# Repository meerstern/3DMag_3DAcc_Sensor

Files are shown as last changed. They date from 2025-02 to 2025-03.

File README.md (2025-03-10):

# 3D加速度/3D磁力センサ変換基板　
# 3D Magnetometer & 3D Accelerometer Board

## 概要 
  * ST製3D加速度/3D磁力センサ[ISM303DAC][1]を搭載した変換基板です 
  * 1つのセンサで3方向の磁界チャンネルと3方向の加速チャンネルを検出可能です    
  * 変換基板に電圧レベル変換を搭載しているため、3.3V/5V系に直結可能です
  * I2C/SPI/INTすべてのピンで電圧レベル変換を介してアクセス可能です  
  * I2CはGrove互換コネクタを搭載しています  
  * Arduino Uno等で利用可能なサンプルコードがあります  

## 仕様  
  * 磁界センサは最大±50ガウス磁気感度があります   
  * 加速度センサは±2/±4/±8/±16gから選択可能です  
  * 16bit分解能、256個のFIFOメモリを搭載しています    
  * SPI/I2Cシリアルインターフェイスを利用可能です
  * 急降下、動作、磁場検出のためのプログラマブルな割り込みに対応    
  * 電源電圧DC2.5V-5.0V  
  * サイズ30mm x25mm (突起部、コネクタ除く)

## 外観
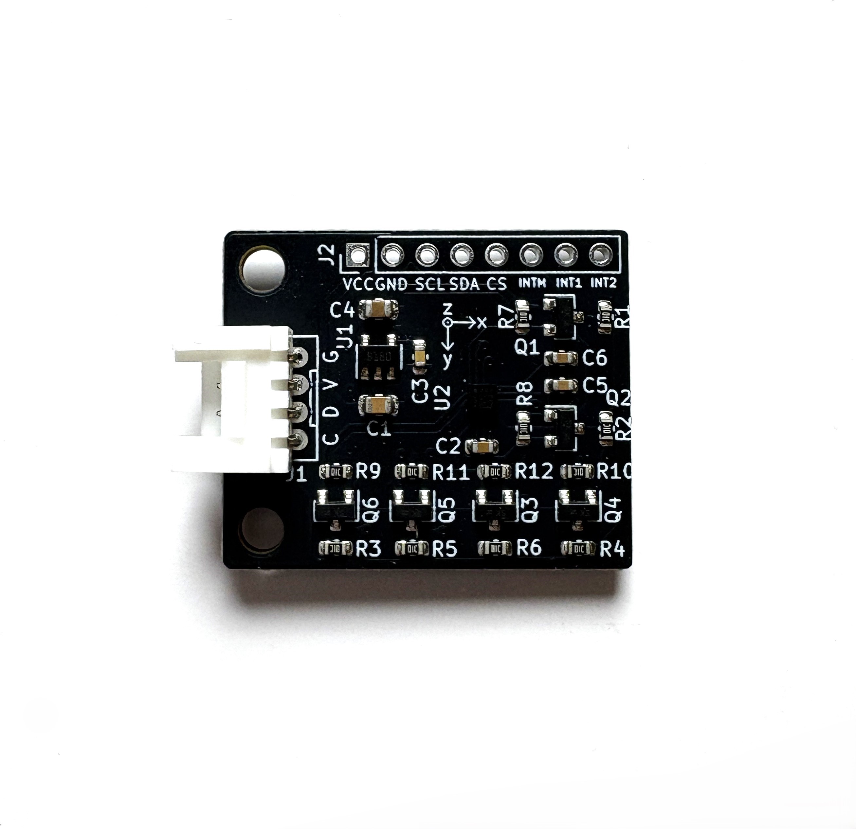
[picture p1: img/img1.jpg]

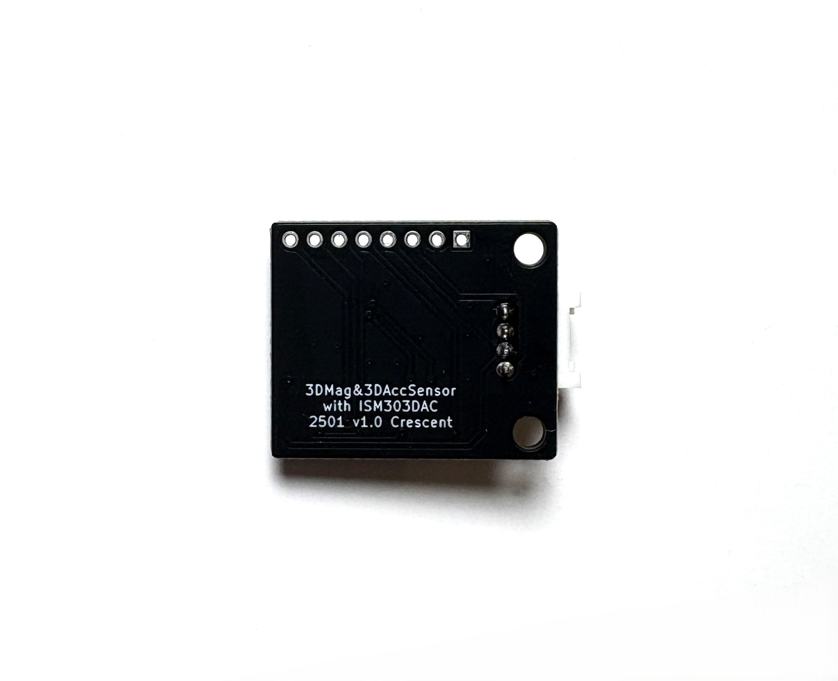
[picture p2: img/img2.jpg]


[1]: https://www.st.com/ja/mems-and-sensors/ism303dac.html

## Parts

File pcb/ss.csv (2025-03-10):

ID | 参照記号 | パッケージ | 数 | 名称 | Supplier and ref
1 | REF2,REF1 | MountingHole_3.2mm_M3 | 2 | MountingHole_3.2mm_M3
2 | U2 | LGA12 | 1 | ISM303DAC
3 | U1 | SOT-23-5 | 1 | LD3985M18R_SOT23
4 | R12,R11,R10,R9,R8,R7,R6,R5,R4,R3,R2,R1 | R_0603_1608Metric | 12 | 10k
5 | Q6,Q5,Q4,Q3,Q2,Q1 | SOT-23 | 6 | Q_NMOS_GSD
6 | J2 | PinHeader_1x08_P2.54mm_Vertical | 1 | Pinheader
7 | J1 | GROVE | 1 | Grove
8 | C6,C5 | C_0603_1608Metric | 2 | 0.1u
9 | C4,C1 | C_0805_2012Metric | 2 | 10u
10 | C3 | C_0603_1608Metric | 1 | 0.01u
11 | C2 | C_0603_1608Metric | 1 | 0.22uF

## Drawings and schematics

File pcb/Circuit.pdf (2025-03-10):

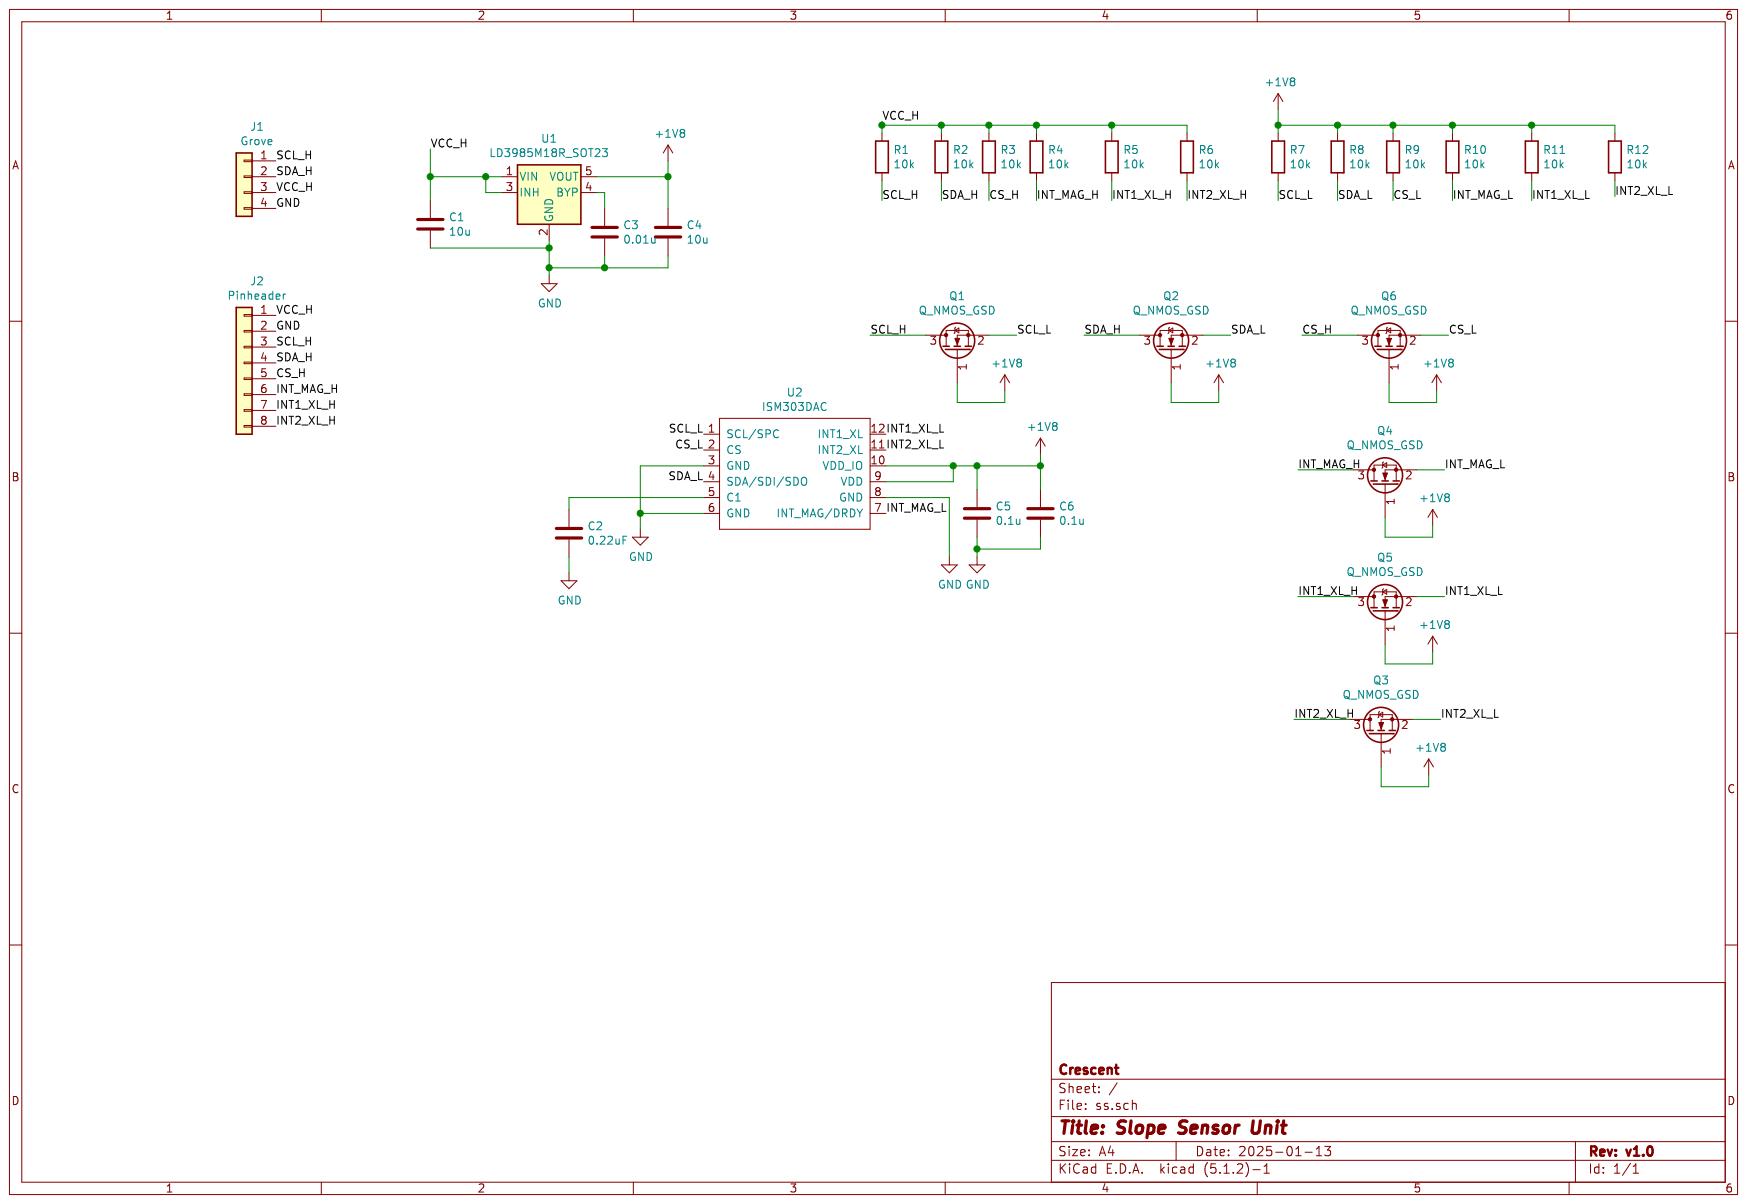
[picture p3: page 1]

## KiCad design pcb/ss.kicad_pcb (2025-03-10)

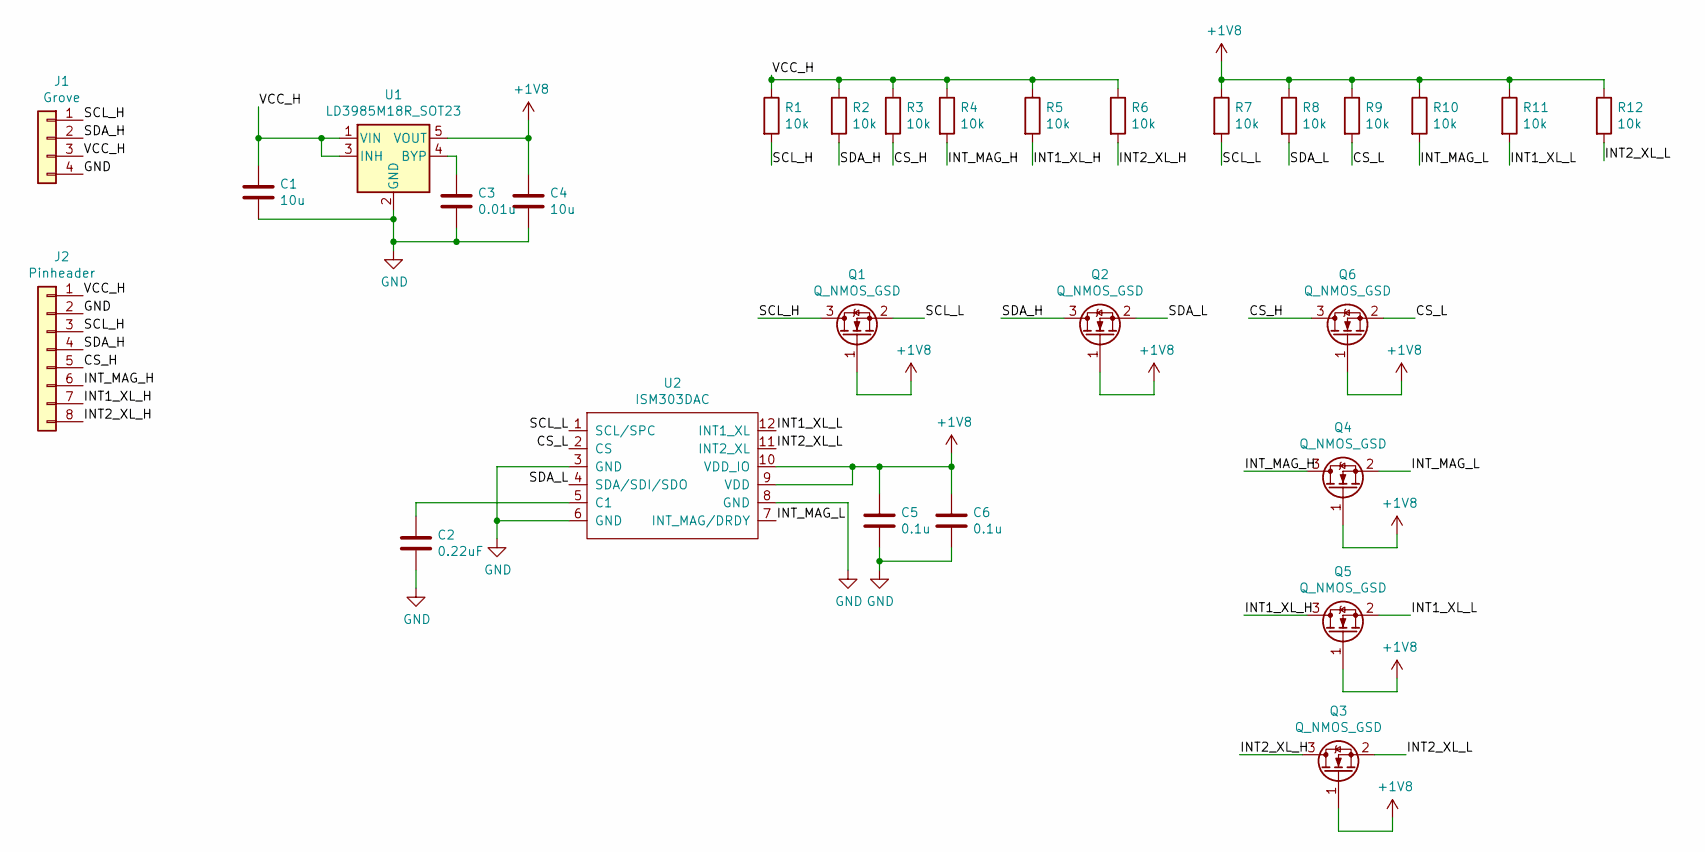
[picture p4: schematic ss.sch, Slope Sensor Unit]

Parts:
C1, C4: 10u; C_0805_2012Metric
C2: 0.22uF; C_0603_1608Metric
C3: 0.01u; C_0603_1608Metric
C5, C6: 0.1u; C_0603_1608Metric
J1: Grove; GROVE
J2: Pinheader; PinHeader_1x08_P2.54mm_Vertical
Q1, Q2, Q3, Q4, Q5, Q6: Q_NMOS_GSD; SOT-23
R1, R2, R3, R4, R5, R6, R7, R8, R9, R10, R11, R12: 10k; R_0603_1608Metric
U1: LD3985M18R_SOT23; SOT-23-5
U2: ISM303DAC; LGA12

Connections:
+1V8: C4.1, C5.1, C6.1, Q1.1 (G), Q2.1 (G), Q3.1 (G), Q4.1 (G), Q5.1 (G), Q6.1 (G), R7.1, R8.1, R9.1, R10.1, R11.1, R12.1, U1.5 (VOUT), U2.9 (VDD), U2.10 (VDD_IO)
/CS_H: J2.5, Q6.3 (D), R3.2
/CS_L: Q6.2 (S), R9.2, U2.2 (CS)
/INT1_XL_H: J2.7, Q5.3 (D), R5.2
/INT1_XL_L: Q5.2 (S), R11.2, U2.12 (INT1_XL)
/INT2_XL_H: J2.8, Q3.3 (D), R6.2
/INT2_XL_L: Q3.2 (S), R12.2, U2.11 (INT2_XL)
/INT_MAG_H: J2.6, Q4.3 (D), R4.2
/INT_MAG_L: Q4.2 (S), R10.2, U2.7 (INT_MAG/DRDY)
/SCL_H: J1.1, J2.3, Q1.3 (D), R1.2
/SCL_L: Q1.2 (S), R7.2, U2.1 (SCL/SPC)
/SDA_H: J1.2, J2.4, Q2.3 (D), R2.2
/SDA_L: Q2.2 (S), R8.2, U2.4 (SDA/SDI/SDO)
/VCC_H: C1.1, J1.3, J2.1, R1.1, R2.1, R3.1, R4.1, R5.1, R6.1, U1.1 (VIN), U1.3 (INH)
GND: C1.2, C2.2, C3.2, C4.2, C5.2, C6.2, J1.4, J2.2, U1.2 (GND), U2.3 (GND), U2.6 (GND), U2.8 (GND)
unnamed: C2.1, U2.5 (C1)
unnamed: C3.1, U1.4 (BYP)

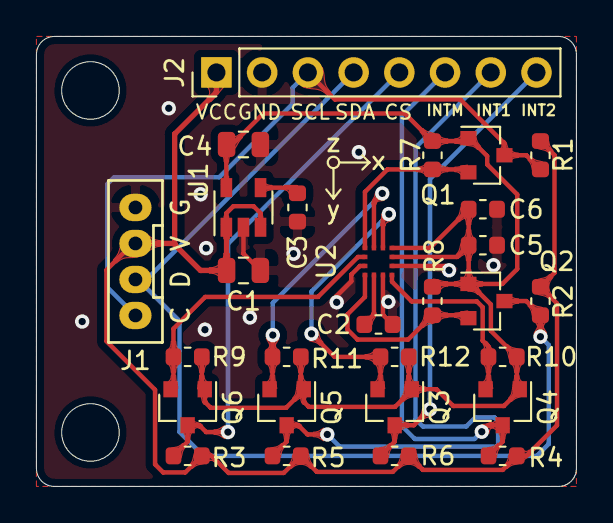
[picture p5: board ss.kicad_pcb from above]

Board: 2 copper layers, 30.0 x 25.0 mm, 30 parts (0 on the bottom side), 17 nets.

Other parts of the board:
REF1, REF2: MountingHole_3.2mm_M3

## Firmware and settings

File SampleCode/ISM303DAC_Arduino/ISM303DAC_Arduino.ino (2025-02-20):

/*
 ******************************************************************************
 * @file    read_data_polling.c
 * @author  Sensor Solutions Software Team
 * @brief   This file show the simplest way to get data from sensor.
 *
 ******************************************************************************
 * @attention
 *
 * <h2><center>&copy; Copyright (c) 2020 STMicroelectronics.
 * All rights reserved.</center></h2>
 *
 * This software component is licensed by ST under BSD 3-Clause license,
 * the "License"; You may not use this file except in compliance with the
 * License. You may obtain a copy of the License at:
 *                        opensource.org/licenses/BSD-3-Clause
 *
 ******************************************************************************
 */
/* Includes ------------------------------------------------------------------*/
#include <Arduino.h>
#include <Wire.h>
#include <string.h>
#include <stdio.h>
#include "ism303dac_reg.h"


typedef struct {
  //void   *hbus;
  uint8_t i2c_address;
  //GPIO_TypeDef *cs_port;
  //uint16_t cs_pin;
} sensbus_t;

/* Private macro -------------------------------------------------------------*/
#define    BOOT_TIME          20 //ms
//#define TX_BUF_DIM          100

#define    WAIT_TIME_XL     200 //ms
#define    WAIT_TIME_01     20 //ms
#define    WAIT_TIME_02     60 //ms

#define    SAMPLES_XL        5 //number of samples
#define    SAMPLES_MG       50 //number of samples
/* Self test limits. */
#define    MIN_ST_LIMIT_mg         70.0f
#define    MAX_ST_LIMIT_mg       1500.0f
#define    MIN_ST_LIMIT_mG         15.0f
#define    MAX_ST_LIMIT_mG        500.0f

/* Self test results. */
#define    ST_PASS     1U
#define    ST_FAIL     0U

/* Private variables ---------------------------------------------------------*/
static sensbus_t xl_bus =  {//&SENSOR_BUS,
                            (ISM303DAC_I2C_ADD_XL>>1)//,
                            //0,
                            //0
                           };
static sensbus_t mag_bus = {//&SENSOR_BUS,
                            (ISM303DAC_I2C_ADD_MG>>1)//,
                           // 0,
                           // 0
                           };


static int16_t data_raw_acceleration[3];
static int16_t data_raw_magnetic[3];
static float_t acceleration_mg[3];
static float_t magnetic_mG[3];
static uint8_t whoamI, rst;
//static uint8_t tx_buffer[TX_BUF_DIM];

/* Extern variables ----------------------------------------------------------*/

/* Private functions ---------------------------------------------------------*/
/*
 *   WARNING:
 *   Functions declare in this section are defined at the end of this file
 *   and are strictly related to the hardware platform used.
 *
 */
static int32_t platform_write(void *handle, uint8_t reg, const uint8_t *bufp,
                              uint16_t len);
static int32_t platform_read(void *handle, uint8_t reg, uint8_t *bufp,
                             uint16_t len);
static void tx_com( uint8_t *tx_buffer, uint16_t len );
static void platform_delay(uint32_t ms);
static void platform_init(void);
void ism303dac_read_data_polling(void);
void ism303dac_self_test(void);

/* Example --------------------------------------------------------------*/
void setup() 
{

  Serial.begin(9600);
  delay(10);
  Serial.println("ISM303DAC Demo");
  delay(10);
  ism303dac_self_test();
  ism303dac_read_data_polling();
}


void loop() 
{
  

}

/* Main Example --------------------------------------------------------------*/
void ism303dac_read_data_polling(void)
{
  /* Initialize mems driver interface */
  stmdev_ctx_t dev_ctx_xl;
  stmdev_ctx_t dev_ctx_mg;
  /* Initialize inertial sensors (IMU) driver interface */
  dev_ctx_xl.write_reg = platform_write;
  dev_ctx_xl.read_reg = platform_read;
  dev_ctx_xl.handle = (void *)&xl_bus;
  /* Initialize magnetic sensors driver interface */
  dev_ctx_mg.write_reg = platform_write;
  dev_ctx_mg.read_reg = platform_read;
  dev_ctx_mg.handle = (void *)&mag_bus;
  /* Initialize platform specific hardware */
  platform_init();
  /* Wait sensor boot time */
  platform_delay(BOOT_TIME);
  /* Check device ID */
  whoamI = 0;
  ism303dac_xl_device_id_get(&dev_ctx_xl, &whoamI);

  if ( whoamI != ISM303DAC_ID_XL )
    while (1); /*manage here device not found */

  whoamI = 0;
  ism303dac_mg_device_id_get(&dev_ctx_mg, &whoamI);

  if ( whoamI != ISM303DAC_ID_MG )
    while (1); /*manage here device not found */

  /* Restore default configuration */
  ism303dac_xl_reset_set(&dev_ctx_xl, PROPERTY_ENABLE);

  do {
    ism303dac_xl_reset_get(&dev_ctx_xl, &rst);
  } while (rst);

  ism303dac_mg_reset_set(&dev_ctx_mg, PROPERTY_ENABLE);

  do {
    ism303dac_mg_reset_get(&dev_ctx_mg, &rst);
  } while (rst);

  /* Enable Block Data Update */
  ism303dac_xl_block_data_update_set(&dev_ctx_xl, PROPERTY_ENABLE);
  ism303dac_mg_block_data_update_set(&dev_ctx_mg, PROPERTY_ENABLE);
  /* Set full scale */
  ism303dac_xl_full_scale_set(&dev_ctx_xl, ISM303DAC_XL_2g);
  /* Configure filtering chain */
  /* Accelerometer - High Pass / Slope path */
  //ism303dac_xl_hp_path_set(&dev_ctx_xl, ISM303DAC_HP_ON_OUTPUTS);
  /* Set / Reset magnetic sensor mode */
  ism303dac_mg_set_rst_mode_set(&dev_ctx_mg,
                                ISM303DAC_MG_SENS_OFF_CANC_EVERY_ODR);
  /* Enable temperature compensation on mag sensor */
  ism303dac_mg_offset_temp_comp_set(&dev_ctx_mg, PROPERTY_ENABLE);
  /* Set Output Data Rate */
  ism303dac_xl_data_rate_set(&dev_ctx_xl, ISM303DAC_XL_ODR_100Hz_LP);
  ism303dac_mg_data_rate_set(&dev_ctx_mg, ISM303DAC_MG_ODR_10Hz);
  /* Set magnetometer in continuous mode */
  ism303dac_mg_operating_mode_set(&dev_ctx_mg,
                                  ISM303DAC_MG_CONTINUOUS_MODE);

  /* Read samples in polling mode (no int) */
  while (1) {
    /* Read output only if new value is available */
    ism303dac_reg_t reg;
    ism303dac_xl_status_reg_get(&dev_ctx_xl, &reg.status_a);

    if (reg.status_a.drdy) {
      /* Read acceleration data */
      memset(data_raw_acceleration, 0x00, 3 * sizeof(int16_t));
      ism303dac_acceleration_raw_get(&dev_ctx_xl, data_raw_acceleration);
      acceleration_mg[0] = ism303dac_from_fs2g_to_mg(
                             data_raw_acceleration[0]);
      acceleration_mg[1] = ism303dac_from_fs2g_to_mg(
                             data_raw_acceleration[1]);
      acceleration_mg[2] = ism303dac_from_fs2g_to_mg(
                             data_raw_acceleration[2]);
      //Arduino Not Supportted snprintf float
      //snprintf((char *)tx_buffer, sizeof(tx_buffer),
      //        "Acceleration [mg]:%4.2f\t%4.2f\t%4.2f\r\n",
      //        acceleration_mg[0], acceleration_mg[1], acceleration_mg[2]);
      //tx_com( tx_buffer, strlen( (char const *)tx_buffer ) );
      Serial.print("Acceleration [mg]:\t\t");    
      Serial.print(acceleration_mg[0]);
      Serial.print(",\t\t");    
      Serial.print(acceleration_mg[1]);
      Serial.print(",\t\t");    
      Serial.print(acceleration_mg[2]);
      Serial.println();
    }

    ism303dac_mg_status_get(&dev_ctx_mg, &reg.status_reg_m);

    if (reg.status_reg_m.zyxda) {
      /* Read magnetic field data */
      memset(data_raw_magnetic, 0x00, 3 * sizeof(int16_t));
      ism303dac_magnetic_raw_get(&dev_ctx_mg, data_raw_magnetic);
      magnetic_mG[0] = ism303dac_from_lsb_to_mG( data_raw_magnetic[0]);
      magnetic_mG[1] = ism303dac_from_lsb_to_mG( data_raw_magnetic[1]);
      magnetic_mG[2] = ism303dac_from_lsb_to_mG( data_raw_magnetic[2]);
      //Arduino Not Supportted snprintf float
      //snprintf((char *)tx_buffer, sizeof(tx_buffer),
      //        "Magnetic field [mG]:%4.2f\t%4.2f\t%4.2f\r\n",
      //       magnetic_mG[0], magnetic_mG[1], magnetic_mG[2]);
      //tx_com( tx_buffer, strlen( (char const *)tx_buffer ) );
      Serial.print("Magnetic field [mG]:\t\t");    
      Serial.print(magnetic_mG[0]);
      Serial.print(",\t\t");    
      Serial.print(magnetic_mG[1]);
      Serial.print(",\t\t");    
      Serial.print(magnetic_mG[2]);
      Serial.println();
    }
  }
}

void ism303dac_self_test(void)
{
  stmdev_ctx_t dev_ctx_xl;
  stmdev_ctx_t dev_ctx_mg;
  uint8_t tx_buffer[1000];
  float_t meas_st_off[3];
  int16_t data_raw[3];
  float_t meas_st_on[3];
  ism303dac_reg_t reg;
  float_t test_val[3];
  uint8_t st_result;
  uint8_t i, j;
  /* Initialize inertial sensors (IMU) driver interface */
  dev_ctx_xl.write_reg = platform_write;
  dev_ctx_xl.read_reg = platform_read;
  dev_ctx_xl.handle = (void *)&xl_bus;
  /* Initialize magnetic sensors driver interface */
  dev_ctx_mg.write_reg = platform_write;
  dev_ctx_mg.read_reg = platform_read;
  dev_ctx_mg.handle = (void *)&mag_bus;
  /* Initialize self test results */
  st_result = ST_PASS;
  /* Initialize platform specific hardware */
  platform_init();
  /* Wait sensor boot time */
  platform_delay(BOOT_TIME);
  /* Check device ID */
  reg.byte = 0;
  ism303dac_xl_device_id_get(&dev_ctx_xl, &reg.byte);

  if ( reg.byte != ISM303DAC_ID_XL )
    while (1); /*manage here device not found */

  reg.byte = 0;
  ism303dac_mg_device_id_get(&dev_ctx_mg, &reg.byte);

  if ( reg.byte != ISM303DAC_ID_MG )
    while (1); /*manage here device not found */

  /* Restore default configuration */
  ism303dac_xl_reset_set(&dev_ctx_xl, PROPERTY_ENABLE);

  do {
    ism303dac_xl_reset_get(&dev_ctx_xl, &reg.byte);
  } while (reg.byte);

  ism303dac_mg_reset_set(&dev_ctx_mg, PROPERTY_ENABLE);

  do {
    ism303dac_mg_reset_get(&dev_ctx_mg, &reg.byte);
  } while (reg.byte);

  /* Enable Block Data Update */
  ism303dac_xl_block_data_update_set(&dev_ctx_xl, PROPERTY_ENABLE);
  ism303dac_mg_block_data_update_set(&dev_ctx_mg, PROPERTY_ENABLE);
  /*
   * START ACCELEROMETER SELF TEST PROCEDURE
   */
  /* Set full scale */
  ism303dac_xl_full_scale_set(&dev_ctx_xl, ISM303DAC_XL_2g);
  /* Set Output Data Rate. */
  ism303dac_xl_data_rate_set(&dev_ctx_xl, ISM303DAC_XL_ODR_50Hz_HR);
  /* Wait stable output */
  platform_delay(WAIT_TIME_XL);

  /* Check if new value available */
  do {
    ism303dac_xl_status_reg_get(&dev_ctx_xl, &reg.status_a);
  } while (!reg.status_a.drdy);

  /* Read dummy data and discard it */
  ism303dac_acceleration_raw_get(&dev_ctx_xl, data_raw);

  /* Read samples and get the average vale for each axis */
  for (i = 0; i < SAMPLES_XL; i++) {
    /* Check if new value available */
    do {
      ism303dac_xl_status_reg_get(&dev_ctx_xl, &reg.status_a);
    } while (!reg.status_a.drdy);

    /* Read data and accumulate the mg value */
    ism303dac_acceleration_raw_get(&dev_ctx_xl, data_raw);

    for (j = 0; j < 3; j++) {
      meas_st_off[j] += ism303dac_from_fs2g_to_mg(data_raw[j]);
    }
  }

  /* Calculate the mg average values */
  for (i = 0; i < 3; i++) {
    meas_st_off[i] /= SAMPLES_XL;
  }

  /* Enable Self Test positive (or negative) */
  ism303dac_xl_self_test_set(&dev_ctx_xl, ISM303DAC_XL_ST_POSITIVE);
  //ism303dac_xl_self_test_set(&dev_ctx_xl, ISM303DAC_ST_NEGATIVE);
  /* Wait stable output */
  platform_delay(WAIT_TIME_XL);

  /* Check if new value available */
  do {
    ism303dac_xl_status_reg_get(&dev_ctx_xl, &reg.status_a);
  } while (!reg.status_a.drdy);

  /* Read dummy data and discard it */
  ism303dac_acceleration_raw_get(&dev_ctx_xl, data_raw);

  /* Read samples and get the average vale for each axis */
  for (i = 0; i < SAMPLES_XL; i++) {
    /* Check if new value available */
    do {
      ism303dac_xl_status_reg_get(&dev_ctx_xl, &reg.status_a);
    } while (!reg.status_a.drdy);

    /* Read data and accumulate the mg value */
    ism303dac_acceleration_raw_get(&dev_ctx_xl, data_raw);

    for (j = 0; j < 3; j++) {
      meas_st_on[j] += ism303dac_from_fs2g_to_mg(data_raw[j]);
    }
  }

  /* Calculate the mg average values */
  for (i = 0; i < 3; i++) {
    meas_st_on[i] /= SAMPLES_XL;
  }

  /* Calculate the mg values for self test */
  for (i = 0; i < 3; i++) {
    test_val[i] = fabsf((meas_st_on[i] - meas_st_off[i]));
  }

  /* Check self test limit */
  for (i = 0; i < 3; i++) {
    if (( MIN_ST_LIMIT_mg > test_val[i] ) ||
        ( test_val[i] > MAX_ST_LIMIT_mg)) {
      st_result = ST_FAIL;
    }

    tx_com(tx_buffer, strlen((char const *)tx_buffer));
  }

  /* Disable Self Test */
  ism303dac_xl_self_test_set(&dev_ctx_xl, ISM303DAC_XL_ST_DISABLE);
  /* Disable sensor. */
  ism303dac_xl_data_rate_set(&dev_ctx_xl, ISM303DAC_XL_ODR_OFF);
  /*
   * END ACCELEROMETER SELF TEST PROCEDURE
   */
  /*
   * START MAGNETOMETER SELF TEST PROCEDURE
   */
  /* Temperature compensation enable */
  ism303dac_mg_offset_temp_comp_set(&dev_ctx_mg, PROPERTY_ENABLE);
  /* Set restore magnetic condition policy */
  ism303dac_mg_set_rst_mode_set(&dev_ctx_mg,
                                ISM303DAC_MG_SET_SENS_ODR_DIV_63);
  /* Set power mode */
  ism303dac_mg_power_mode_set(&dev_ctx_mg,
                              ISM303DAC_MG_HIGH_RESOLUTION);
  /* Set Output Data Rate */
  ism303dac_mg_data_rate_set(&dev_ctx_mg, ISM303DAC_MG_ODR_100Hz);
  /* Set Operating mode */
  ism303dac_mg_operating_mode_set(&dev_ctx_mg,
                                  ISM303DAC_MG_CONTINUOUS_MODE);
  /* Wait stable output */
  platform_delay(WAIT_TIME_01);

  /* Check if new value available */
  do {
    ism303dac_mg_status_get(&dev_ctx_mg, &reg.status_reg_m);
  } while (!reg.status_reg_m.zyxda);

  /* Read dummy data and discard it */
  ism303dac_magnetic_raw_get(&dev_ctx_mg, data_raw);
  /* Read samples and get the average vale for each axis */
  memset(meas_st_off, 0x00, 3 * sizeof(float));

  for (i = 0; i < SAMPLES_MG; i++) {
    /* Check if new value available */
    do {
      ism303dac_mg_status_get(&dev_ctx_mg, &reg.status_reg_m);
    } while (!reg.status_reg_m.zyxda);

    /* Read data and accumulate the mg value */
    ism303dac_magnetic_raw_get(&dev_ctx_mg, data_raw);

    for (j = 0; j < 3; j++) {
      meas_st_off[j] += ism303dac_from_lsb_to_mG(data_raw[j]);
    }
  }

  /* Calculate the mg average values */
  for (i = 0; i < 3; i++) {
    meas_st_off[i] /= SAMPLES_MG;
  }

  /* Enable Self Test */
  ism303dac_mg_self_test_set(&dev_ctx_mg, PROPERTY_ENABLE);
  /* Wait stable output */
  platform_delay(WAIT_TIME_02);

  /* Check if new value available */
  do {
    ism303dac_mg_status_get(&dev_ctx_mg, &reg.status_reg_m);
  } while (!reg.status_reg_m.zyxda);

  /* Read dummy data and discard it */
  ism303dac_magnetic_raw_get(&dev_ctx_mg, data_raw);
  /* Read samples and get the average vale for each axis */
  memset(meas_st_on, 0x00, 3 * sizeof(float));

  for (i = 0; i < SAMPLES_MG; i++) {
    /* Check if new value available */
    do {
      ism303dac_mg_status_get(&dev_ctx_mg, &reg.status_reg_m);
    } while (!reg.status_reg_m.zyxda);

    /* Read data and accumulate the mg value */
    ism303dac_magnetic_raw_get(&dev_ctx_mg, data_raw);

    for (j = 0; j < 3; j++) {
      meas_st_on[j] += ism303dac_from_lsb_to_mG(data_raw[j]);
    }
  }

  /* Calculate the mg average values */
  for (i = 0; i < 3; i++) {
    meas_st_on[i] /= SAMPLES_MG;
  }

  st_result = ST_PASS;

  /* Calculate the mg values for self test */
  for (i = 0; i < 3; i++) {
    test_val[i] = fabsf((meas_st_on[i] - meas_st_off[i]));
  }

  /* Check self test limit */
  for (i = 0; i < 3; i++) {
    if (( MIN_ST_LIMIT_mG > test_val[i] ) ||
        ( test_val[i] > MAX_ST_LIMIT_mG)) {
      st_result = ST_FAIL;
    }
  }

  /* Disable Self Test */
  ism303dac_mg_self_test_set(&dev_ctx_mg, PROPERTY_DISABLE);
  /* Disable sensor. */
  ism303dac_mg_operating_mode_set(&dev_ctx_mg, ISM303DAC_MG_POWER_DOWN);

  /*
   * END MAGNETOMETER SELF TEST PROCEDURE
   */

  /* Print self test result */
  if (st_result == ST_PASS) {
    //snprintf((char *)tx_buffer, sizeof(tx_buffer), "Self Test - PASS\r\n" );
    Serial.println("Self Test - PASS");
  }

  else {
    //snprintf((char *)tx_buffer, sizeof(tx_buffer), "Self Test - FAIL\r\n" );
    Serial.println("Self Test - FAIL");
  }

  //tx_com(tx_buffer, strlen((char const *)tx_buffer));
}

/*
 * @brief  Write generic device register (platform dependent)
 *
 * @param  handle    customizable argument. In this examples is used in
 *                   order to select the correct sensor bus handler.
 * @param  reg       register to write
 * @param  bufp      pointer to data to write in register reg
 * @param  len       number of consecutive register to write
 *
 */
static int32_t platform_write(void *handle, uint8_t reg, const uint8_t *bufp,
                              uint16_t len)
{
  sensbus_t *sensbus = (sensbus_t *)handle;

  Wire.beginTransmission(sensbus->i2c_address);
  Wire.write(reg);
  Wire.write(bufp, len);
  Wire.endTransmission();
  return 0;
}

/*
 * @brief  Read generic device register (platform dependent)
 *
 * @param  handle    customizable argument. In this examples is used in
 *                   order to select the correct sensor bus handler.
 * @param  reg       register to read
 * @param  bufp      pointer to buffer that store the data read
 * @param  len       number of consecutive register to read
 *
 */
static int32_t platform_read(void *handle, uint8_t reg, uint8_t *bufp,
                             uint16_t len)
{
  sensbus_t *sensbus = (sensbus_t *)handle;
  
  Wire.beginTransmission(sensbus->i2c_address);
  Wire.write(reg);
  Wire.endTransmission(false);
  
  Wire.requestFrom((uint8_t)sensbus->i2c_address, (uint8_t)len);

  while (Wire.available()) {
    *bufp = Wire.read();
    bufp++;
  }
  return 0;
}

/*
 * @brief  Write generic device register (platform dependent)
 *
 * @param  tx_buffer     buffer to transmit
 * @param  len           number of byte to send
 *
 */
static void tx_com(uint8_t *tx_buffer, uint16_t len)
{

}

/*
 * @brief  platform specific delay (platform dependent)
 *
 * @param  ms        delay in ms
 *
 */
static void platform_delay(uint32_t ms)
{
  delay(ms);
}

/*
 * @brief  platform specific initialization (platform dependent)
 */
static void platform_init(void)
{
  Wire.begin();
  Wire.setClock(100000);
}

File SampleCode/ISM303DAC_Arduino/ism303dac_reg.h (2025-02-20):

/**
  ******************************************************************************
  * @file    ism303dac_reg.h
  * @author  Sensors Software Solution Team
  * @brief   This file contains all the functions prototypes for the
  *          ism303dac_reg.c driver.
  ******************************************************************************
  * @attention
  *
  * <h2><center>&copy; Copyright (c) 2021 STMicroelectronics.
  * All rights reserved.</center></h2>
  *
  * This software component is licensed by ST under BSD 3-Clause license,
  * the "License"; You may not use this file except in compliance with the
  * License. You may obtain a copy of the License at:
  *                        opensource.org/licenses/BSD-3-Clause
  *
  ******************************************************************************
  */

/* Define to prevent recursive inclusion -------------------------------------*/
#ifndef ISM303DAC_REGS_H
#define ISM303DAC_REGS_H

#ifdef __cplusplus
extern "C" {
#endif

/* Includes ------------------------------------------------------------------*/
#include <stdint.h>
#include <stddef.h>
#include <math.h>

/** @addtogroup ISM303DAC
  * @{
  *
  */

/** @defgroup  Endianness definitions
  * @{
  *
  */

#ifndef DRV_BYTE_ORDER
#ifndef __BYTE_ORDER__

#define DRV_LITTLE_ENDIAN 1234
#define DRV_BIG_ENDIAN    4321

/** if _BYTE_ORDER is not defined, choose the endianness of your architecture
  * by uncommenting the define which fits your platform endianness
  */
//#define DRV_BYTE_ORDER    DRV_BIG_ENDIAN
#define DRV_BYTE_ORDER    DRV_LITTLE_ENDIAN

#else /* defined __BYTE_ORDER__ */

#define DRV_LITTLE_ENDIAN  __ORDER_LITTLE_ENDIAN__
#define DRV_BIG_ENDIAN     __ORDER_BIG_ENDIAN__
#define DRV_BYTE_ORDER     __BYTE_ORDER__

#endif /* __BYTE_ORDER__*/
#endif /* DRV_BYTE_ORDER */

/**
  * @}
  *
  */

/** @defgroup STMicroelectronics sensors common types
  * @{
  *
  */

#ifndef MEMS_SHARED_TYPES
#define MEMS_SHARED_TYPES

typedef struct
{
#if DRV_BYTE_ORDER == DRV_LITTLE_ENDIAN
  uint8_t bit0       : 1;
  uint8_t bit1       : 1;
  uint8_t bit2       : 1;
  uint8_t bit3       : 1;
  uint8_t bit4       : 1;
  uint8_t bit5       : 1;
  uint8_t bit6       : 1;
  uint8_t bit7       : 1;
#elif DRV_BYTE_ORDER == DRV_BIG_ENDIAN
  uint8_t bit7       : 1;
  uint8_t bit6       : 1;
  uint8_t bit5       : 1;
  uint8_t bit4       : 1;
  uint8_t bit3       : 1;
  uint8_t bit2       : 1;
  uint8_t bit1       : 1;
  uint8_t bit0       : 1;
#endif /* DRV_BYTE_ORDER */
} bitwise_t;

#define PROPERTY_DISABLE                (0U)
#define PROPERTY_ENABLE                 (1U)

/** @addtogroup  Interfaces_Functions
  * @brief       This section provide a set of functions used to read and
  *              write a generic register of the device.
  *              MANDATORY: return 0 -> no Error.
  * @{
  *
  */

typedef int32_t (*stmdev_write_ptr)(void *, uint8_t, const uint8_t *, uint16_t);
typedef int32_t (*stmdev_read_ptr)(void *, uint8_t, uint8_t *, uint16_t);
typedef void (*stmdev_mdelay_ptr)(uint32_t millisec);

typedef struct
{
  /** Component mandatory fields **/
  stmdev_write_ptr  write_reg;
  stmdev_read_ptr   read_reg;
  /** Component optional fields **/
  stmdev_mdelay_ptr   mdelay;
  /** Customizable optional pointer **/
  void *handle;
} stmdev_ctx_t;

typedef float float_t;

/**
  * @}
  *
  */

#endif /* MEMS_SHARED_TYPES */

#ifndef MEMS_UCF_SHARED_TYPES
#define MEMS_UCF_SHARED_TYPES

/** @defgroup    Generic address-data structure definition
  * @brief       This structure is useful to load a predefined configuration
  *              of a sensor.
  *              You can create a sensor configuration by your own or using
  *              Unico / Unicleo tools available on STMicroelectronics
  *              web site.
  *
  * @{
  *
  */

typedef struct
{
  uint8_t address;
  uint8_t data;
} ucf_line_t;

/**
  * @}
  *
  */

#endif /* MEMS_UCF_SHARED_TYPES */

/**
  * @}
  *
  */

/** @defgroup ism303dac_Infos
  * @{
  *
  */

/** I2C Device Address 8 bit format **/
#define ISM303DAC_I2C_ADD_XL       0x3BU
#define ISM303DAC_I2C_ADD_MG       0x3DU

/** Device Identification (Who am I) **/
#define ISM303DAC_ID_XL            0x43U
#define ISM303DAC_ID_MG            0x40U

/**
  * @}
  *
  */

#define ISM303DAC_MODULE_8BIT_A           0x0CU
#define ISM303DAC_WHO_AM_I_A              0x0FU
#define ISM303DAC_CTRL1_A                 0x20U
typedef struct
{
#if DRV_BYTE_ORDER == DRV_LITTLE_ENDIAN
  uint8_t bdu                 : 1;
  uint8_t hf_odr              : 1;
  uint8_t fs                  : 2;
  uint8_t odr                 : 4;
#elif DRV_BYTE_ORDER == DRV_BIG_ENDIAN
  uint8_t odr                 : 4;
  uint8_t fs                  : 2;
  uint8_t hf_odr              : 1;
  uint8_t bdu                 : 1;
#endif /* DRV_BYTE_ORDER */
} ism303dac_ctrl1_a_t;

#define ISM303DAC_CTRL2_A                 0x21U
typedef struct
{
#if DRV_BYTE_ORDER == DRV_LITTLE_ENDIAN
  uint8_t sim                 : 1;
  uint8_t i2c_disable         : 1;
  uint8_t if_add_inc          : 1;
  uint8_t fds_slope           : 1;
  uint8_t not_used_01         : 2;
  uint8_t soft_reset          : 1;
  uint8_t boot                : 1;
#elif DRV_BYTE_ORDER == DRV_BIG_ENDIAN
  uint8_t boot                : 1;
  uint8_t soft_reset          : 1;
  uint8_t not_used_01         : 2;
  uint8_t fds_slope           : 1;
  uint8_t if_add_inc          : 1;
  uint8_t i2c_disable         : 1;
  uint8_t sim                 : 1;
#endif /* DRV_BYTE_ORDER */
} ism303dac_ctrl2_a_t;

#define ISM303DAC_CTRL3_A                 0x22U
typedef struct
{
#if DRV_BYTE_ORDER == DRV_LITTLE_ENDIAN
  uint8_t pp_od               : 1;
  uint8_t h_lactive           : 1;
  uint8_t lir                 : 1;
  uint8_t tap_z_en            : 1;
  uint8_t tap_y_en            : 1;
  uint8_t tap_x_en            : 1;
  uint8_t st                  : 2;
#elif DRV_BYTE_ORDER == DRV_BIG_ENDIAN
  uint8_t st                  : 2;
  uint8_t tap_x_en            : 1;
  uint8_t tap_y_en            : 1;
  uint8_t tap_z_en            : 1;
  uint8_t lir                 : 1;
  uint8_t h_lactive           : 1;
  uint8_t pp_od               : 1;
#endif /* DRV_BYTE_ORDER */
} ism303dac_ctrl3_a_t;

#define ISM303DAC_CTRL4_A                 0x23U
typedef struct
{
#if DRV_BYTE_ORDER == DRV_LITTLE_ENDIAN
  uint8_t int1_drdy           : 1;
  uint8_t int1_fth            : 1;
  uint8_t int1_6d             : 1;
  uint8_t int1_tap            : 1;
  uint8_t int1_ff             : 1;
  uint8_t int1_wu             : 1;
  uint8_t int1_s_tap          : 1;
  uint8_t not_used_01         : 1;
#elif DRV_BYTE_ORDER == DRV_BIG_ENDIAN
  uint8_t not_used_01         : 1;
  uint8_t int1_s_tap          : 1;
  uint8_t int1_wu             : 1;
  uint8_t int1_ff             : 1;
  uint8_t int1_tap            : 1;
  uint8_t int1_6d             : 1;
  uint8_t int1_fth            : 1;
  uint8_t int1_drdy           : 1;
#endif /* DRV_BYTE_ORDER */
} ism303dac_ctrl4_a_t;
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

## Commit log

2025-02-20 Add Sample Code
2025-03-10 Add pcb
    [ss-B_Cu.gbl, ss-B_Mask.gbs, ss-B_Paste.gbp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]
2025-03-10 Add Circuit

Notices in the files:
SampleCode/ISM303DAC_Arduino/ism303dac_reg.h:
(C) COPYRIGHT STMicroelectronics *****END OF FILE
